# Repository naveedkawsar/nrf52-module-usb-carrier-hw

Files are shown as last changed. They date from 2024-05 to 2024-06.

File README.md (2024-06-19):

# nrf52-module-usb-carrier-hw
USB-powered demo board for an E73-2G4M04S1B BLE module (based on the nRF52832) with some peripherals

<!--
![pcb front view](pics/render-pcb-front.PNG)
![pcb back view](pics/render-pcb-back.PNG)
-->

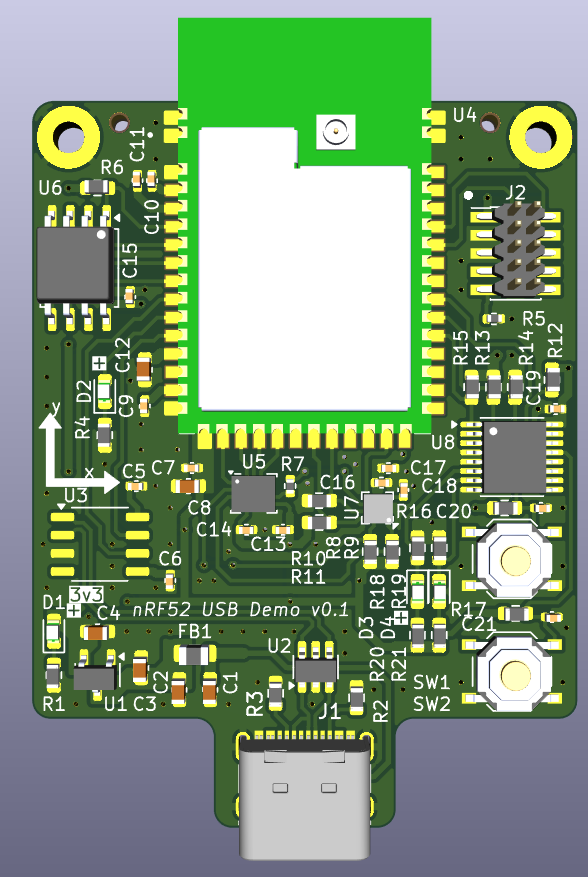
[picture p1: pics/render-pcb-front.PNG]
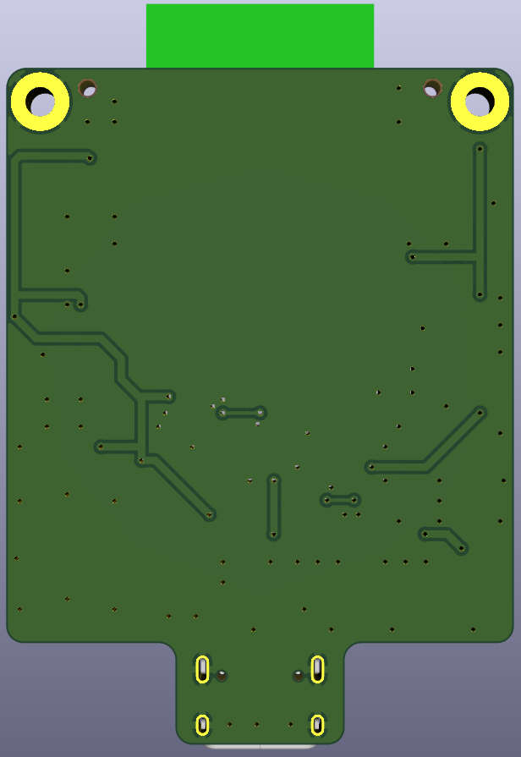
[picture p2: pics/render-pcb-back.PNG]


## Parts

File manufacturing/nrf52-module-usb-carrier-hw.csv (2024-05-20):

Reference | Value | Datasheet | Footprint | Qty | DNP | LCSC Part #
C1,C2,C3,C4,C8,C12 | 4u7 | https://mm.digikey.com/Volume0/opasdata/d220001/medias/docus/2328/CL10A475KO8NNNC_Spec.pdf | Capacitor_SMD:C_0603_1608Metric | 6 |  | C19666
C5,C6,C7,C9,C10,C11,C13,C14,C15,C16,C17,C18,C19,C20,C21 | 100nF | https://mm.digikey.com/Volume0/opasdata/d220001/medias/docus/609/CL05B104KO5NNNC.pdf | Capacitor_SMD:C_0402_1005Metric | 15 |  | C1525
D1,D2,D3,D4 | 19-217/GHC-YR1S2/6T | https://datasheet.lcsc.com/lcsc/2207051802_Everlight-Elec-19-217-GHC-YR1S2-6T_C2986059.pdf | LED_SMD:LED_0603_1608Metric | 4 |  | C2986059
FB1 | GZ2012D101TF | https://www.sunlordinc.com//uploads/files/20230829/GZ%20series%20of%20Multilayer%20Chip%20Ferrite%20Bead.pdf | Inductor_SMD:L_0805_2012Metric | 1 |  | C1015
J1 | USB_C_Receptacle_USB2.0_16P | https://www.usb.org/sites/default/files/documents/usb_type-c.zip | Connector_USB:USB_C_Receptacle_XKB_U262-16XN-4BVC11 | 1 |  | C319148
J2 | Conn_ARM_JTAG_SWD_10 | http://infocenter.arm.com/help/topic/com.arm.doc.ddi0314h/DDI0314H_coresight_components_trm.pdf | Connector_PinHeader_1.27mm:PinHeader_2x05_P1.27mm_Vertical_SMD | 1 |  | C598540
R1,R4,R20,R21 | 1k | https://datasheet.lcsc.com/lcsc/2206010130_UNI-ROYAL-Uniroyal-Elec-0603WAF1001T5E_C21190.pdf | Resistor_SMD:R_0603_1608Metric | 4 |  | C21190
R2,R3,R6,R8,R9,R10,R11,R12,R13,R14,R15,R16,R17,R18,R19 | 5k1 | https://wmsc.lcsc.com/wmsc/upload/file/pdf/v2/lcsc/2206010116_UNI-ROYAL-Uniroyal-Elec-0603WAF5101T5E_C23186.pdf | Resistor_SMD:R_0603_1608Metric | 15 |  | C23186
R5,R7 | 0R | https://datasheet.lcsc.com/lcsc/2206010216_UNI-ROYAL-Uniroyal-Elec-0402WGF0000TCE_C17168.pdf | Resistor_SMD:R_0402_1005Metric | 2 |  | C17168
SW1,SW2 | SW_Push | https://datasheet.lcsc.com/lcsc/2304140030_XKB-Connection-TS-1187A-B-A-B_C318884.pdf | Button_Switch_SMD:SW_Push_1P1T_XKB_TS-1187A | 2 |  | C318884
U1 | XC6206PxxxMR | https://www.torexsemi.com/file/xc6206/XC6206.pdf | Package_TO_SOT_SMD:SOT-23-3 | 1 |  | C5446
U2 | USBLC6-2SC6 | https://www.st.com/resource/en/datasheet/usblc6-2.pdf | Package_TO_SOT_SMD:SOT-23-6 | 1 |  | C2827654
U3 | CH340N | https://aitendo3.sakura.ne.jp/aitendo_data/product_img/ic/inteface/CH340N/ch340n.pdf | Package_SO:SOP-8_3.9x4.9mm_P1.27mm | 1 |  | C2977777
U4 | E73-2G4M04S1B | https://datasheet.lcsc.com/lcsc/2204121100_Chengdu-Ebyte-Elec-Tech-E73-2G4M04S1B_C411306.pdf | E73-2G4M04S1B:XCVR_E73-2G4M04S1B | 1 |  | C411306
U5 | LSM6DSO | https://www.st.com/resource/en/datasheet/lsm6dsox.pdf | Package_LGA:LGA-14_3x2.5mm_P0.5mm_LayoutBorder3x4y | 1 |  | C2829074
U6 | W25Q128JVS | http://www.winbond.com/resource-files/w25q128jv_dtr%20revc%2003272018%20plus.pdf | Package_SO:SOIC-8_5.23x5.23mm_P1.27mm | 1 |  | C97521
U7 | LIS3MDL | https://www.st.com/resource/en/datasheet/lis3mdl.pdf | Package_LGA:LGA-12_2x2mm_P0.5mm | 1 |  | C478483
U8 | PCA9557PW | https://www.nxp.com/docs/en/data-sheet/PCA9557.pdf | Package_SO:TSSOP-16_4.4x5mm_P0.65mm | 1 |  | C141380

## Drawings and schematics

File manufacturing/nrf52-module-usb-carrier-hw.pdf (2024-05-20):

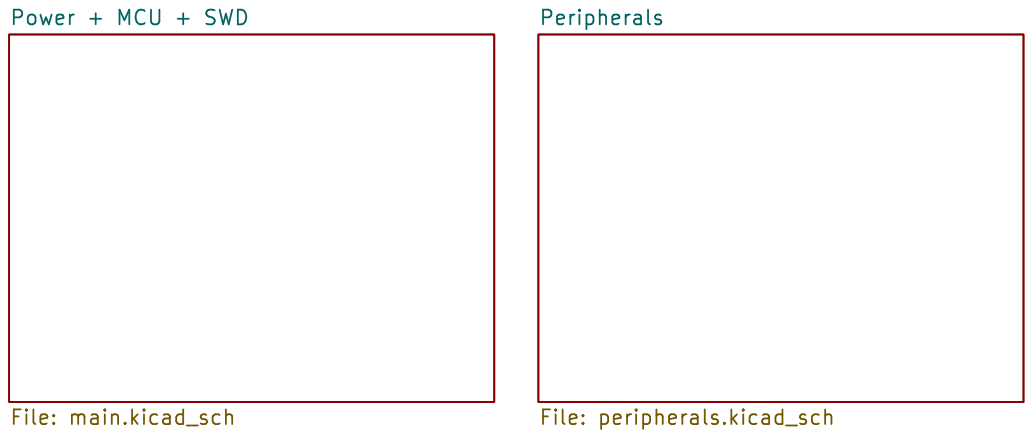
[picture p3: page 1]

Peripherals File: peripherals.kicad_sch Power + MCU + SWD

Id: 1/3 Title: File: nrf52-module-usb-carrier-hw.kicad_sch Sheet: /

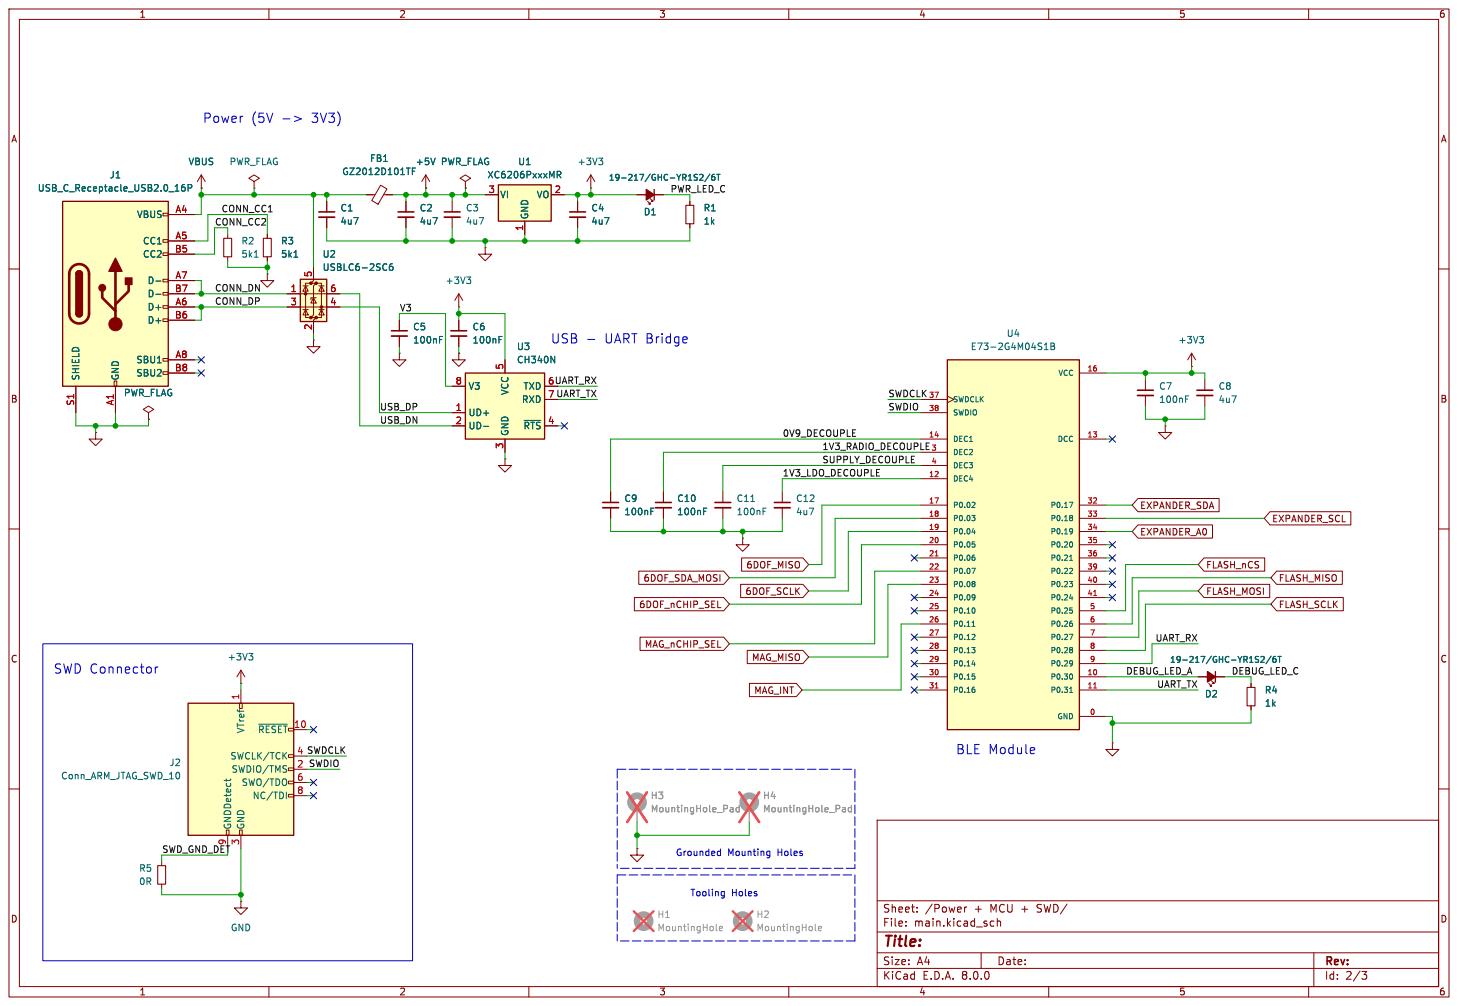
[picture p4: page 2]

5 TXD 6 RXD 7 V3 8 U3 CH340N GNDVTref 1 ~{RESET}10 SWDIO/TMS 2 GND

3 SWCLK/TCK 4 SWO/TDO 6 NC/TDI 8 GNDDetect 9

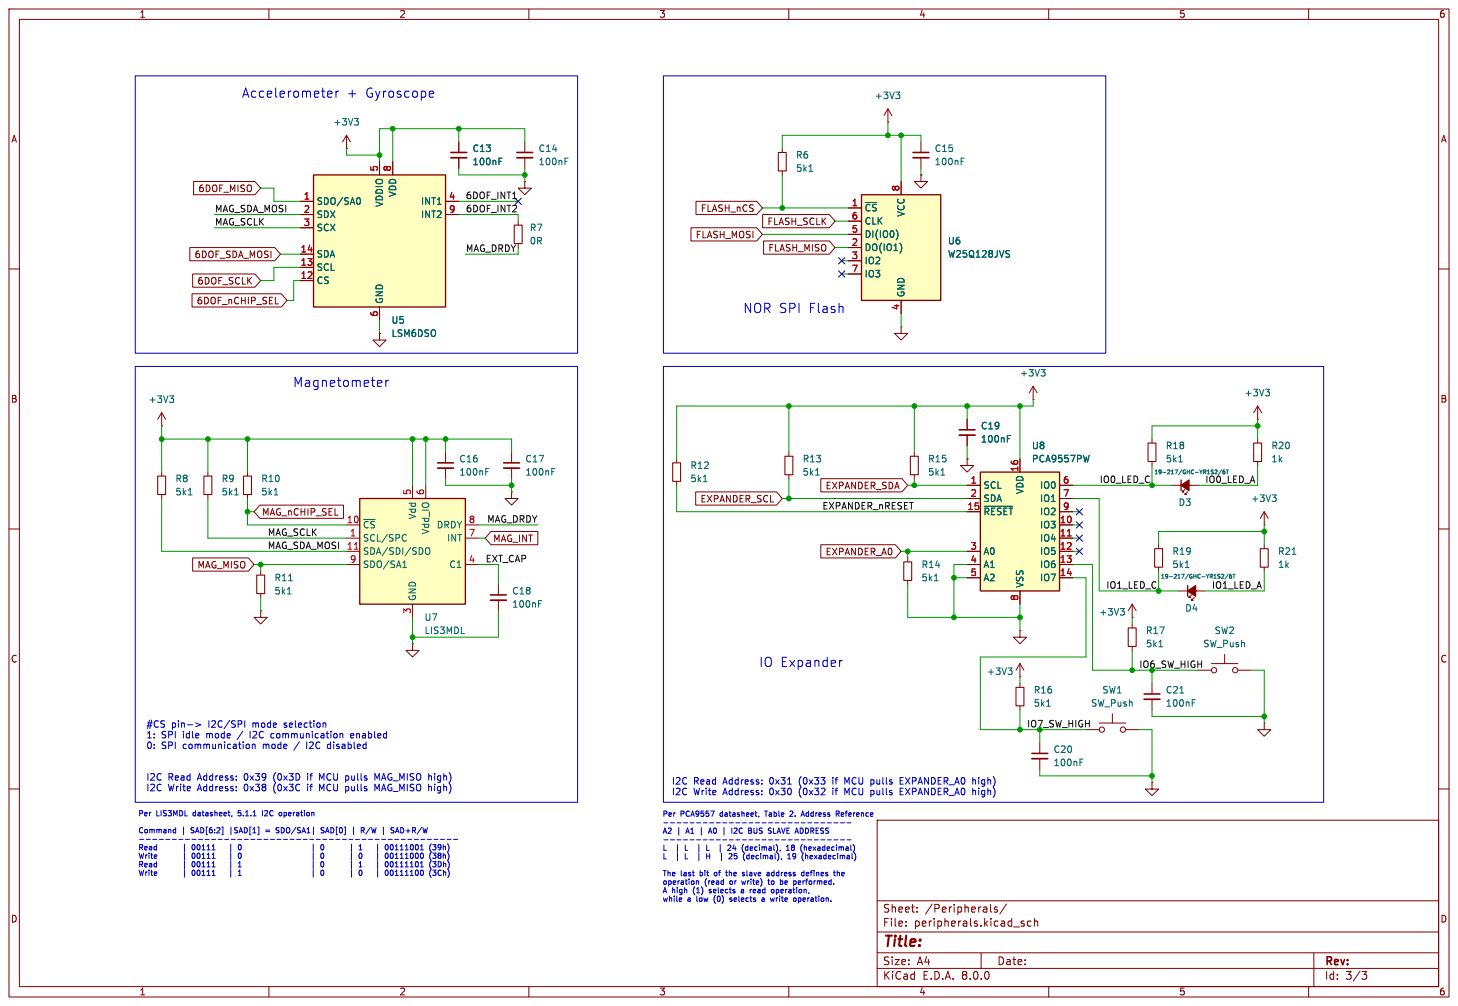
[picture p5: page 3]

I2C Read Address: 0x39 (0x3D if MCU pulls MAG_MISO high)

I2C Write Address: 0x30 (0x32 if MCU pulls EXPANDER_A0 high)

Id: 3/3 Title: File: peripherals.kicad_sch Sheet: /Peripherals/

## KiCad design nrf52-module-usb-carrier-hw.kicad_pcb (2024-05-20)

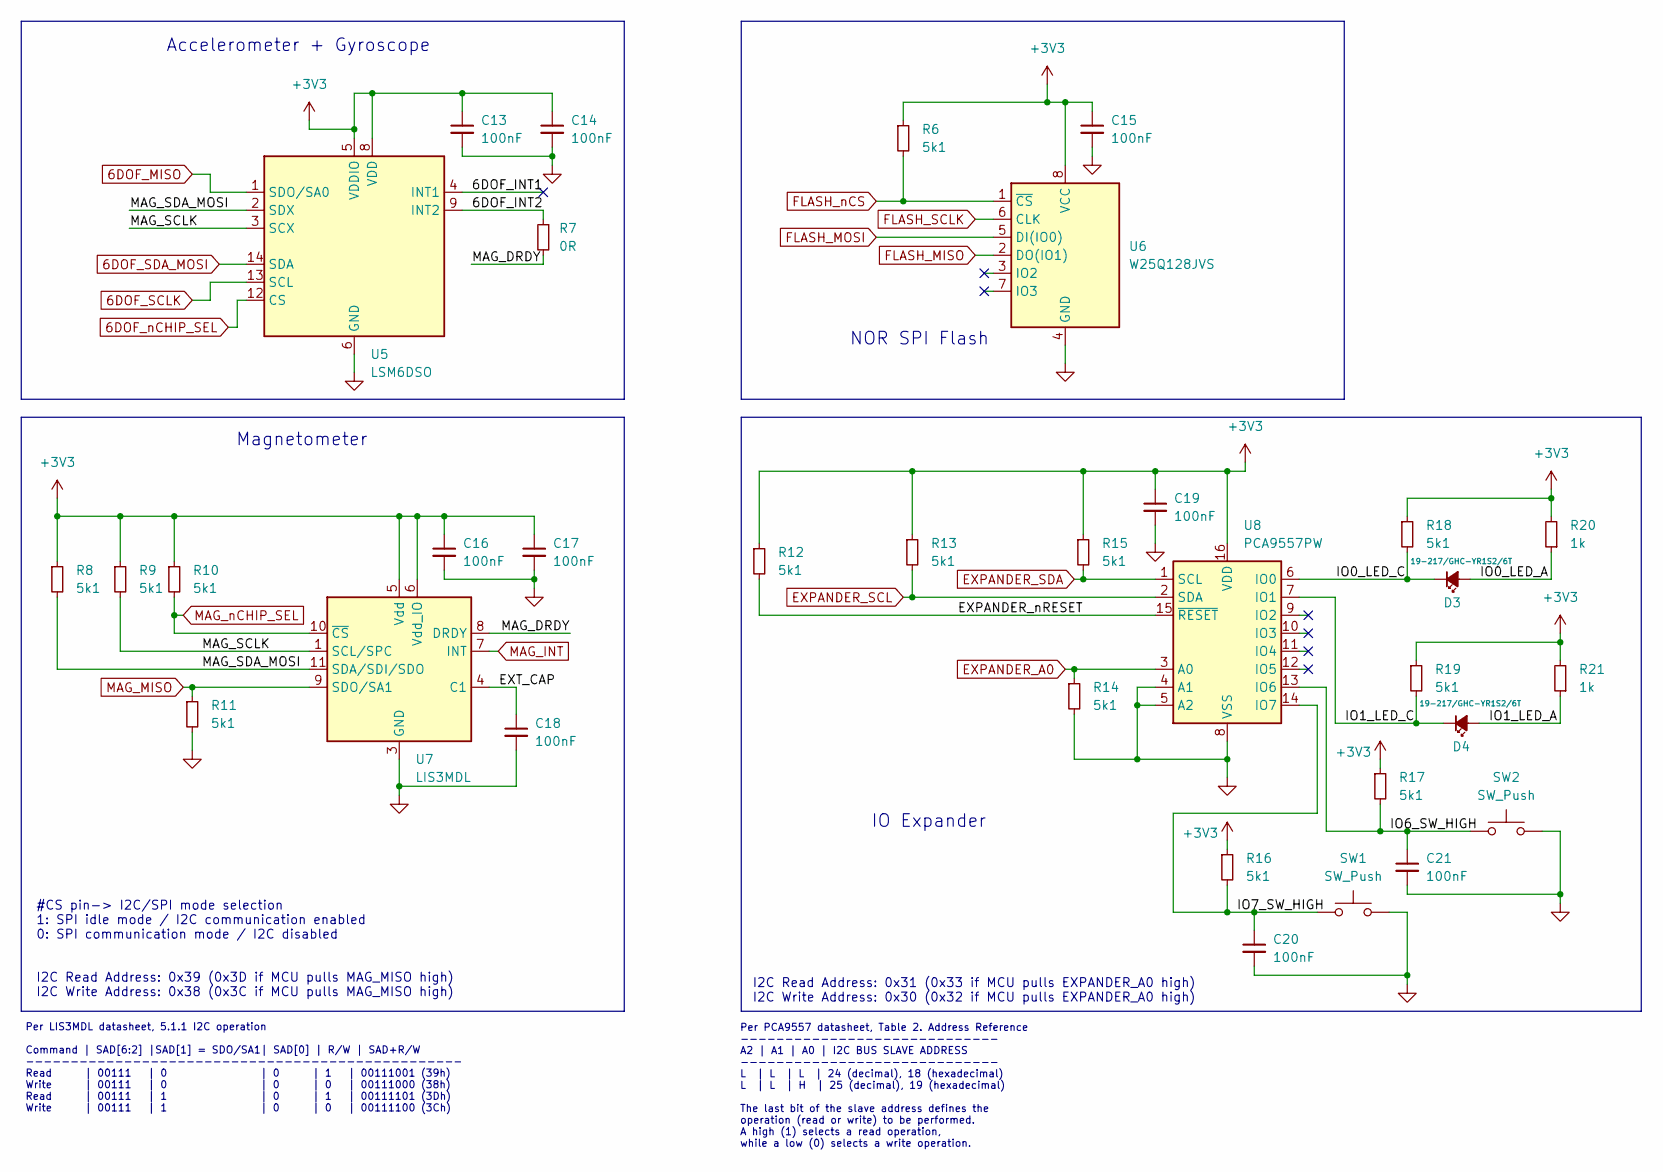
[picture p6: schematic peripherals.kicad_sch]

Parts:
C13, C14, C15, C16, C17, C18, C19, C20, C21: 100nF; C_0402_1005Metric; Manufacturer Part Number CL05B104KO5NNNC; LCSC Part # C1525
D3, D4: 19-217/GHC-YR1S2/6T; LED_0603_1608Metric; Manufacturer Part Number 19-217/GHC-YR1S2/6T; LCSC Part # C2986059
R6, R8, R9, R10, R11, R12, R13, R14, R15, R16, R17, R18, R19: 5k1; R_0603_1608Metric; Manufacturer Part Number 0603WAF5101T5E; LCSC Part # C23186
R7: 0R; R_0402_1005Metric; Manufacturer Part Number 0402WGF0000TCE; LCSC Part # C17168
R20, R21: 1k; R_0603_1608Metric; Manufacturer Part Number 0603WAF1001T5E; LCSC Part # C21190
SW1, SW2: SW_Push; SW_Push_1P1T_XKB_TS-1187A; LCSC Part # C318884
U5: LSM6DSO; LGA-14_3x2.5mm_P0.5mm_LayoutBorder3x4y; Manufacturer Part Number LSM6DSOTR; LCSC Part # C2829074
U6: W25Q128JVS; SOIC-8_5.23x5.23mm_P1.27mm; Manufacturer Part Number W25Q128JVSIQ; LCSC Part # C97521
U7: LIS3MDL; LGA-12_2x2mm_P0.5mm; Manufacturer Part Number LIS3MDLTR; LCSC Part # C478483
U8: PCA9557PW; TSSOP-16_4.4x5mm_P0.65mm; LCSC Part # C141380

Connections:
6DOF_MISO: U5.1 (SDO/SA0); also elsewhere on the board
6DOF_SCLK: U5.13 (SCL); also elsewhere on the board
6DOF_SDA_MOSI: U5.14 (SDA); also elsewhere on the board
6DOF_nCHIP_SEL: U5.12 (CS); also elsewhere on the board
+3V3: C13.1, C14.1, C15.1, C16.1, C17.1, C19.1, R6.1, R8.1, R9.1, R10.1, R12.1, R13.1, R15.1, R16.1, R17.1, R18.1, R19.1, R20.2, R21.2, U5.5 (VDDIO), U5.8 (VDD), U6.8 (VCC), U7.5 (Vdd), U7.6 (Vdd_IO), U8.16 (VDD); also elsewhere on the board
/Peripherals/6DOF_INT1: U5.4 (INT1)
/Peripherals/6DOF_INT2: R7.1, U5.9 (INT2)
/Peripherals/EXPANDER_nRESET: R12.2, U8.15 (~RESET)
/Peripherals/EXT_CAP: C18.1, U7.4 (C1)
/Peripherals/IO0_LED_A: D3.2 (A), R20.1
/Peripherals/IO0_LED_C: D3.1 (K), R18.2, U8.6 (IO0)
/Peripherals/IO1_LED_A: D4.2 (A), R21.1
/Peripherals/IO1_LED_C: D4.1 (K), R19.2, U8.7 (IO1)
/Peripherals/IO6_SW_HIGH: C21.1, R17.2, SW2.1, U8.13 (IO6)
/Peripherals/IO7_SW_HIGH: C20.1, R16.2, SW1.1, U8.14 (IO7)
/Peripherals/MAG_DRDY: R7.2, U7.8 (DRDY)
/Peripherals/MAG_SCLK: R9.2, U5.3 (SCX), U7.1 (SCL/SPC)
/Peripherals/MAG_SDA_MOSI: R8.2, U5.2 (SDX), U7.11 (SDA/SDI/SDO)
EXPANDER_A0: R14.1, U8.3 (A0); also elsewhere on the board
EXPANDER_SCL: R13.2, U8.2 (SDA); also elsewhere on the board
EXPANDER_SDA: R15.2, U8.1 (SCL); also elsewhere on the board
FLASH_MISO: U6.2 (DO(IO1)); also elsewhere on the board
FLASH_MOSI: U6.5 (DI(IO0)); also elsewhere on the board
FLASH_SCLK: U6.6 (CLK); also elsewhere on the board
FLASH_nCS: R6.2, U6.1 (~CS); also elsewhere on the board
GND: C13.2, C14.2, C15.2, C16.2, C17.2, C18.2, C19.2, C20.2, C21.2, R11.2, R14.2, SW1.2, SW2.2, U5.6 (GND), U5.7 (GND), U6.4 (GND), U7.2 (GND), U7.3 (GND), U7.12 (GND), U8.4 (A1), U8.5 (A2), U8.8 (VSS); also elsewhere on the board
MAG_INT: U7.7 (INT); also elsewhere on the board
MAG_MISO: R11.1, U7.9 (SDO/SA1); also elsewhere on the board
MAG_nCHIP_SEL: R10.2, U7.10 (~CS); also elsewhere on the board

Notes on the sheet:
Magnetometer
NOR SPI Flash
Accelerometer + Gyroscope
IO Expander
I2C Read Address: 0x39 (0x3D if MCU pulls MAG_MISO high) I2C Write Address: 0x38 (0x3C if MCU pulls MAG_MISO high)
Per LIS3MDL datasheet, 5.1.1 I2C operation Command | SAD[6:2] |SAD[1] = SDO/SA1| SAD[0] | R/W | SAD+R/W ------------------------------------------------- Read | 00111 | 0 | 0 | 1 | 00111001 (39h) Write | 00111 | 0 | 0 | 0 | 00111000 (38h) Read | 00111 | 1 | 0 | 1 | 00111101 (3Dh) Write | 00111 | 1 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
Per PCA9557 datasheet, Table 2. Address Reference ----------------------------- A2 | A1 | A0 | I2C BUS SLAVE ADDRESS ----------------------------- L | L | L | 24 (decimal), 18 (hexadecimal) L | L | H | 25 (decimal), 19 (hexadecimal) The last bit of the slave address defines the operation (read or w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
I2C Read Address: 0x31 (0x33 if MCU pulls EXPANDER_A0 high) I2C Write Address: 0x30 (0x32 if MCU pulls EXPANDER_A0 high)
#CS pin-> I2C/SPI mode selection 1: SPI idle mode / I2C communication enabled 0: SPI communication mode / I2C disabled

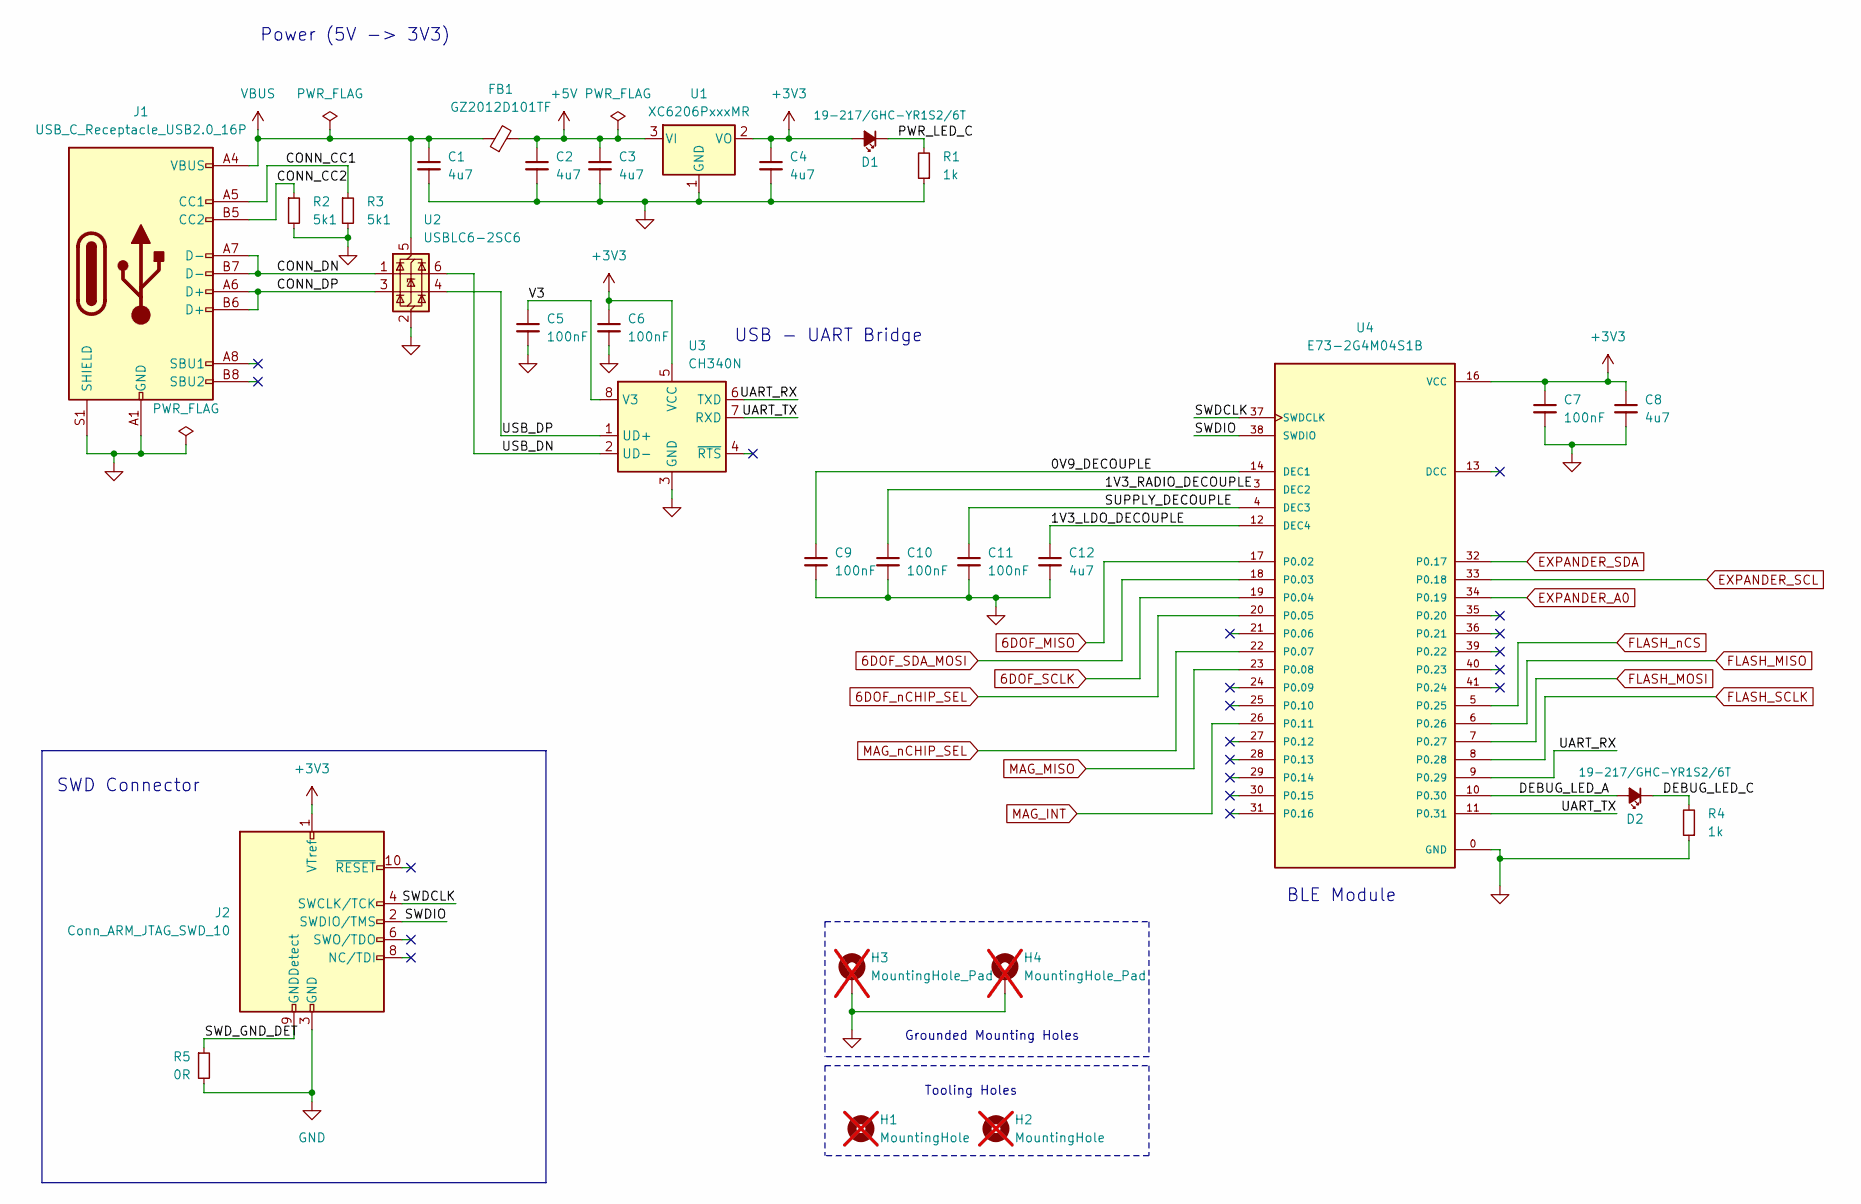
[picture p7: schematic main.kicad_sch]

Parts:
C1, C2, C3, C4, C8, C12: 4u7; C_0603_1608Metric; Manufacturer Part Number CL10A475KO8NNNC; LCSC Part # C19666
C5, C6, C7, C9, C10, C11: 100nF; C_0402_1005Metric; Manufacturer Part Number CL05B104KO5NNNC; LCSC Part # C1525
D1, D2: 19-217/GHC-YR1S2/6T; LED_0603_1608Metric; Manufacturer Part Number 19-217/GHC-YR1S2/6T; LCSC Part # C2986059
FB1: GZ2012D101TF; L_0805_2012Metric; Manufacturer Part Number GZ1608D101TF; LCSC Part # C1015
H1, H2: MountingHole; JLCPCB_ToolingHole_45.4mils; not fitted
H3, H4: MountingHole_Pad; MountingHole_2.2mm_M2_Pad; not fitted
J1: USB_C_Receptacle_USB2.0_16P; USB_C_Receptacle_XKB_U262-16XN-4BVC11; Manufacturer Part Number U262-161N-4BVC11; LCSC Part # C319148
J2: Conn_ARM_JTAG_SWD_10; PinHeader_2x05_P1.27mm_Vertical_SMD; Manufacturer Part Number 20021121-00010T4LF; LCSC Part # C598540
R1, R4: 1k; R_0603_1608Metric; Manufacturer Part Number 0603WAF1001T5E; LCSC Part # C21190
R2, R3: 5k1; R_0603_1608Metric; Manufacturer Part Number 0603WAF5101T5E; LCSC Part # C23186
R5: 0R; R_0402_1005Metric; Manufacturer Part Number 0402WGF0000TCE; LCSC Part # C17168
U1: XC6206PxxxMR; SOT-23-3; Manufacturer Part Number XC6206P332MR-G; LCSC Part # C5446
U2: USBLC6-2SC6; SOT-23-6; Manufacturer Part Number USBLC6-2SC6; LCSC Part # C2827654
U3: CH340N; SOP-8_3.9x4.9mm_P1.27mm; Manufacturer Part Number CH340N; LCSC Part # C2977777
U4: E73-2G4M04S1B; XCVR_E73-2G4M04S1B; PARTREV 1.4; LCSC Part # C411306

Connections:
6DOF_MISO: U4.17 (P0.02); also elsewhere on the board
6DOF_SCLK: U4.19 (P0.04); also elsewhere on the board
6DOF_SDA_MOSI: U4.18 (P0.03); also elsewhere on the board
6DOF_nCHIP_SEL: U4.20 (P0.05); also elsewhere on the board
+3V3: C4.1, C6.1, C7.1, C8.1, D1.2 (A), J2.1 (VTref), U1.2 (VO), U3.5 (VCC), U4.16 (VCC); also elsewhere on the board
+5V: C2.1, C3.1, FB1.2, U1.3 (VI)
/Power + MCU + SWD/0V9_DECOUPLE: C9.1, U4.14 (DEC1)
/Power + MCU + SWD/1V3_LDO_DECOUPLE: C12.1, U4.12 (DEC4)
/Power + MCU + SWD/1V3_RADIO_DECOUPLE: C10.1, U4.3 (DEC2)
/Power + MCU + SWD/CONN_CC1: J1.A5 (CC1), R3.1
/Power + MCU + SWD/CONN_CC2: J1.B5 (CC2), R2.1
/Power + MCU + SWD/CONN_DN: J1.A7 (D-), J1.B7 (D-), U2.1 (I/O1)
/Power + MCU + SWD/CONN_DP: J1.A6 (D+), J1.B6 (D+), U2.3 (I/O2)
/Power + MCU + SWD/DEBUG_LED_A: D2.2 (A), U4.10 (P0.30)
/Power + MCU + SWD/DEBUG_LED_C: D2.1 (K), R4.2
/Power + MCU + SWD/PWR_LED_C: D1.1 (K), R1.2
/Power + MCU + SWD/SUPPLY_DECOUPLE: C11.1, U4.4 (DEC3)
/Power + MCU + SWD/SWDCLK: J2.4 (SWCLK/TCK), U4.37 (SWDCLK)
/Power + MCU + SWD/SWDIO: J2.2 (SWDIO/TMS), U4.38 (SWDIO)
/Power + MCU + SWD/SWD_GND_DET: J2.9 (GNDDetect), R5.1
/Power + MCU + SWD/UART_RX: U3.6 (TXD), U4.9 (P0.29)
/Power + MCU + SWD/UART_TX: U3.7 (RXD), U4.11 (P0.31)
/Power + MCU + SWD/USB_DN: U2.6 (I/O1), U3.2 (UD-)
/Power + MCU + SWD/USB_DP: U2.4 (I/O2), U3.1 (UD+)
/Power + MCU + SWD/V3: C5.1, U3.8 (V3)
EXPANDER_A0: U4.34 (P0.19); also elsewhere on the board
EXPANDER_SCL: U4.33 (P0.18); also elsewhere on the board
EXPANDER_SDA: U4.32 (P0.17); also elsewhere on the board
FLASH_MISO: U4.6 (P0.26); also elsewhere on the board
FLASH_MOSI: U4.7 (P0.27); also elsewhere on the board
FLASH_SCLK: U4.8 (P0.28); also elsewhere on the board
FLASH_nCS: U4.5 (P0.25); also elsewhere on the board
GND: C1.2, C2.2, C3.2, C4.2, C5.2, C6.2, C7.2, C8.2, C9.2, C10.2, C11.2, C12.2, H3.1, H4.1, J1.A1 (GND), J1.A12 (GND), J1.B1 (GND), J1.B12 (GND), J1.S1 (SHIELD), J2.3 (GND), J2.5 (GND), R1.1, R2.2, R3.2, R4.1, R5.2, U1.1 (GND), U2.2 (GND), U3.3 (GND), U4.0 (GND), U4.1 (GND), U4.2 (GND), U4.15 (GND), U4.42 (GND), U4.43 (GND); also elsewhere on the board
MAG_INT: U4.26 (P0.11); also elsewhere on the board
MAG_MISO: U4.23 (P0.08); also elsewhere on the board
MAG_nCHIP_SEL: U4.22 (P0.07); also elsewhere on the board
VBUS: C1.1, FB1.1, J1.A4 (VBUS), J1.A9 (VBUS), J1.B4 (VBUS), J1.B9 (VBUS), U2.5 (VBUS)

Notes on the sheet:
USB - UART Bridge
Grounded Mounting Holes
Tooling Holes
Power (5V -> 3V3)
BLE Module
SWD Connector

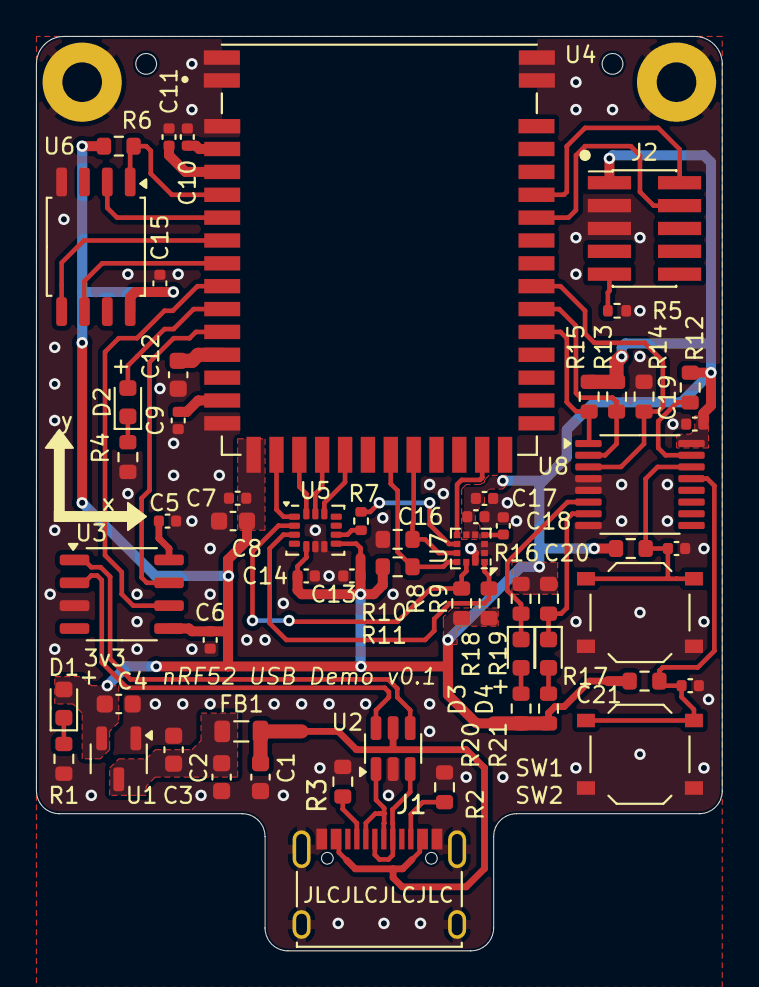
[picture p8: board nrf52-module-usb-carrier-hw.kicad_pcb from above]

Board: 2 copper layers, 38.1 x 50.8 mm, 63 parts (0 on the bottom side), 49 nets.

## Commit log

2024-05-14 Initial commit of schematic with nRF module, SPI Flash, IMU sensors. Plus PCB file with WIP placement of module and USB connectors
    [main.kicad_sch, nrf52-module-usb-carrier-hw.kicad_pcb, nrf52-module-usb-carrier-hw.kicad_sch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]
2024-05-16 Routed diff pairs, IMU sensors, SPI Flash
    [main.kicad_sch, nrf52-module-usb-carrier-hw.kicad_pcb]
2024-05-19 Added an I2C IO expander, plus 2 pushbuttons and 2 LEDs controlled by the expander
    [main.kicad_sch, nrf52-module-usb-carrier-hw.kicad_pcb, peripherals.kicad_sch]
2024-05-19 PWR and GND netclass cleanup
    [nrf52-module-usb-carrier-hw.kicad_pcb]
2024-05-19 Started routing power
    [nrf52-module-usb-carrier-hw.kicad_pcb]
2024-05-19 Updated PCB file to handle DRC. No errors, few warnings remaining
    [nrf52-module-usb-carrier-hw.kicad_pcb]
2024-05-19 Cleaned up schematic with comments from datasheets. Added stitching vias to PCB
    [main.kicad_sch, nrf52-module-usb-carrier-hw.kicad_pcb, peripherals.kicad_sch]
2024-05-19 Switched around debug LED pinout with a UART line to be compatible with a previous design
    [main.kicad_sch, nrf52-module-usb-carrier-hw.kicad_pcb]
2024-05-20 Brought out INT pin from magnetometer to MCU, in case of need. Updated layout accordingly
    [main.kicad_sch, nrf52-module-usb-carrier-hw.kicad_pcb, peripherals.kicad_sch]
2024-05-20 Exported BOM, pick-and-place files. Finalized schematic and exported PDF. Files used to place JLCPCB order
    [main.kicad_sch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]
2024-06-19 Added ReadMe with KiCAD render screenshots
